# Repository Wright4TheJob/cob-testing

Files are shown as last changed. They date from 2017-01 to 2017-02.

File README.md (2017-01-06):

# cob-testing
Software for evaluation of cob blocks being tested at The University of Tulsa.
The data logging program monitors ambient temperature and humidity and internal moisture for up to 8 direct moisture resistance sensors. Data is taken at regular intervals and written at each interval to a text file for insurance against power outage. 

The system is built on a raspberry pi, currently running on a Pi 2 model B.

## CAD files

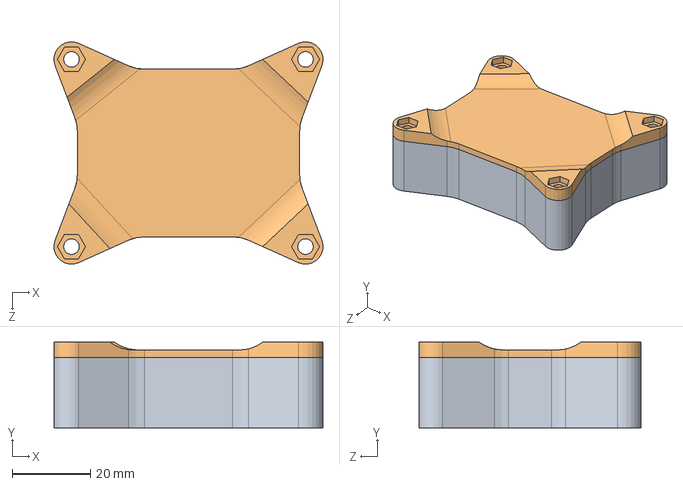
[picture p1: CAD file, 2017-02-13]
Electronics/Case/Assembly.SLDASM
69.0 x 22.0 x 57.0 mm
SensorHubTop
SensorHubPlate

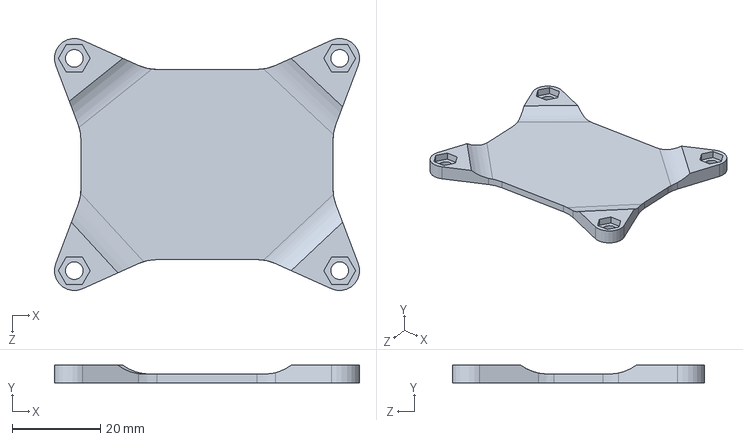
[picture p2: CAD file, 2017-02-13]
Electronics/Case/SensorHubPlate.SLDPRT
69.0 x 4.00 x 57.0 mm

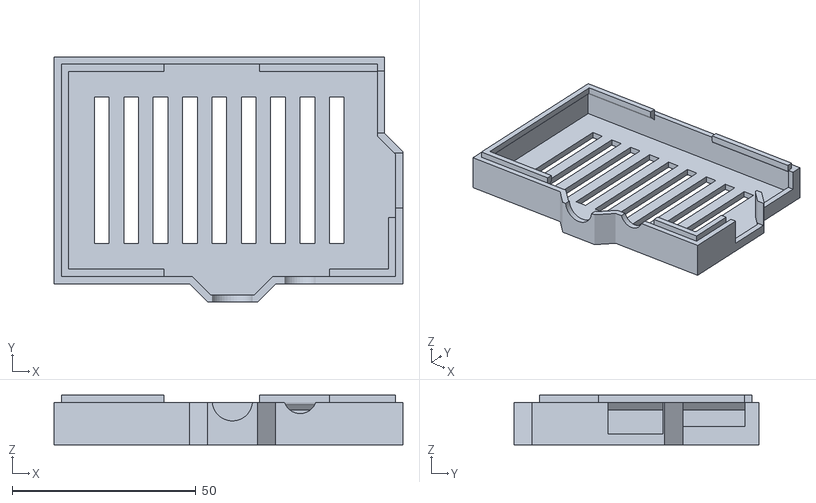
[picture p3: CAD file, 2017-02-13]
Electronics/Case/RasPi_Case2_Top_Vented.stl
95.0 x 66.8 x 13.5

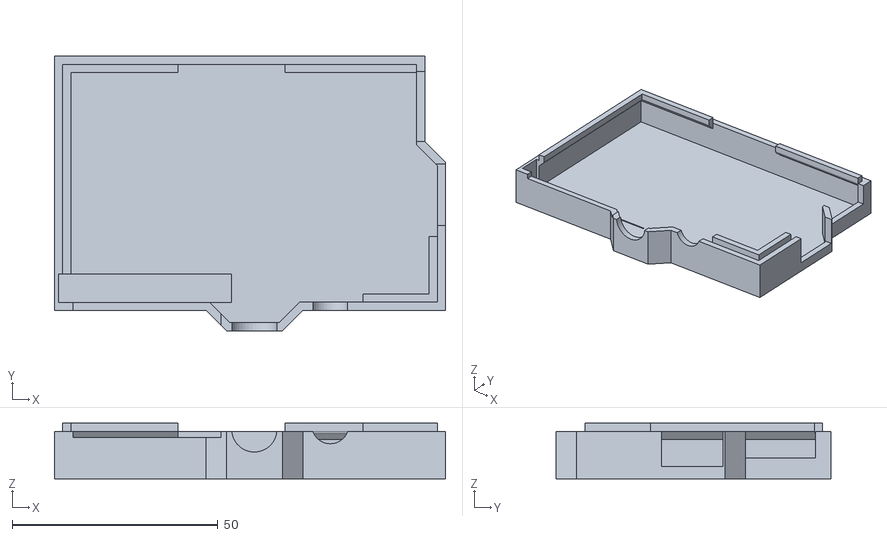
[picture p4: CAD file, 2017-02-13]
Electronics/Case/ModifiedTop.stl
95.0 x 66.8 x 13.5

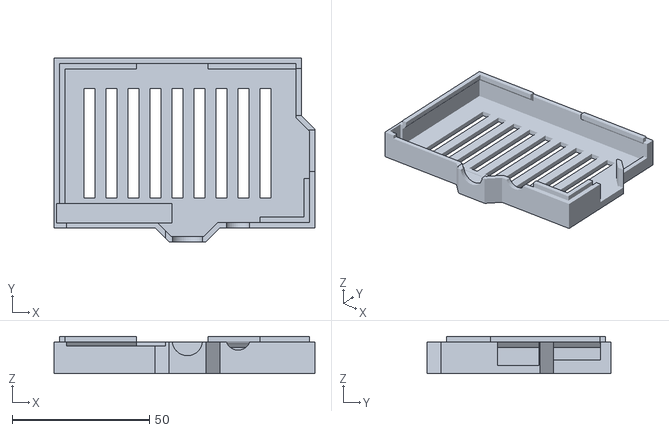
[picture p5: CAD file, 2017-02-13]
Electronics/Case/ModifiedTopVented.stl
95.0 x 66.8 x 13.5

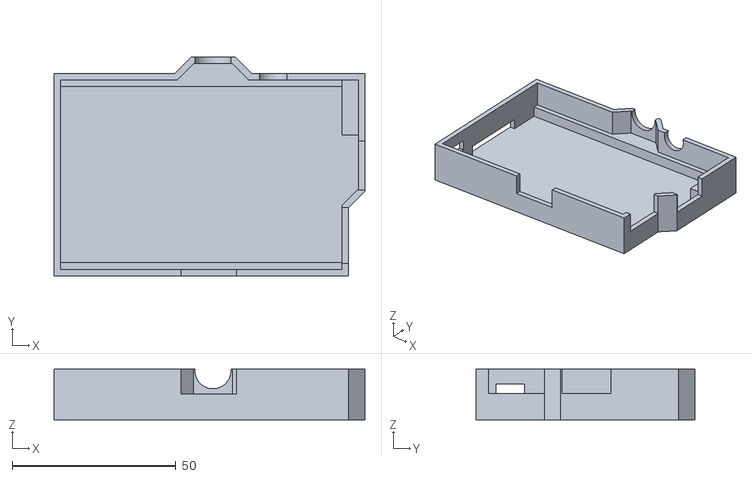
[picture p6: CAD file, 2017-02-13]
Electronics/Case/RasPi_Case2_Bottom_Final.stl
95.0 x 66.8 x 15.5

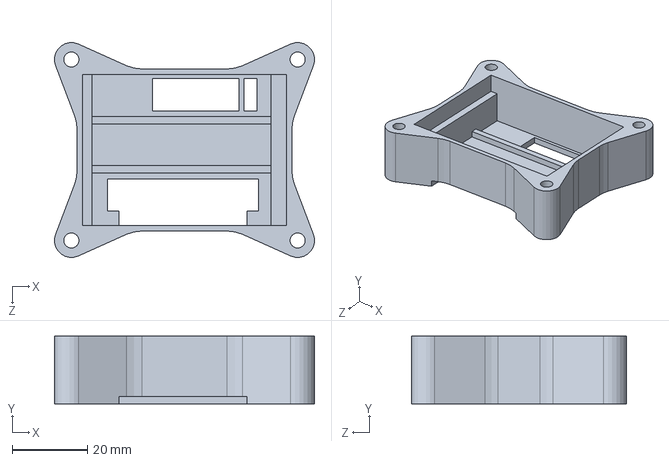
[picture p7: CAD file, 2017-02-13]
Electronics/Case/SensorHubTop.SLDPRT
69.0 x 18.0 x 57.0 mm

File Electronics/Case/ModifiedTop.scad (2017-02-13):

difference() {
    import("RasPi_Case2_Top_Vented.stl", convexity=20);
    translate([-43,-38,10])cube([36,15,5],centering=false);
    translate([-46.5,-26.5,1.75])cube([42,7,15],centering=false);
}

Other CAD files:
Electronics/Case/RasPi_Case2_Top.stl
Electronics/Case/SensorHubPlate.STL
Electronics/Case/SensorHubTop.STL

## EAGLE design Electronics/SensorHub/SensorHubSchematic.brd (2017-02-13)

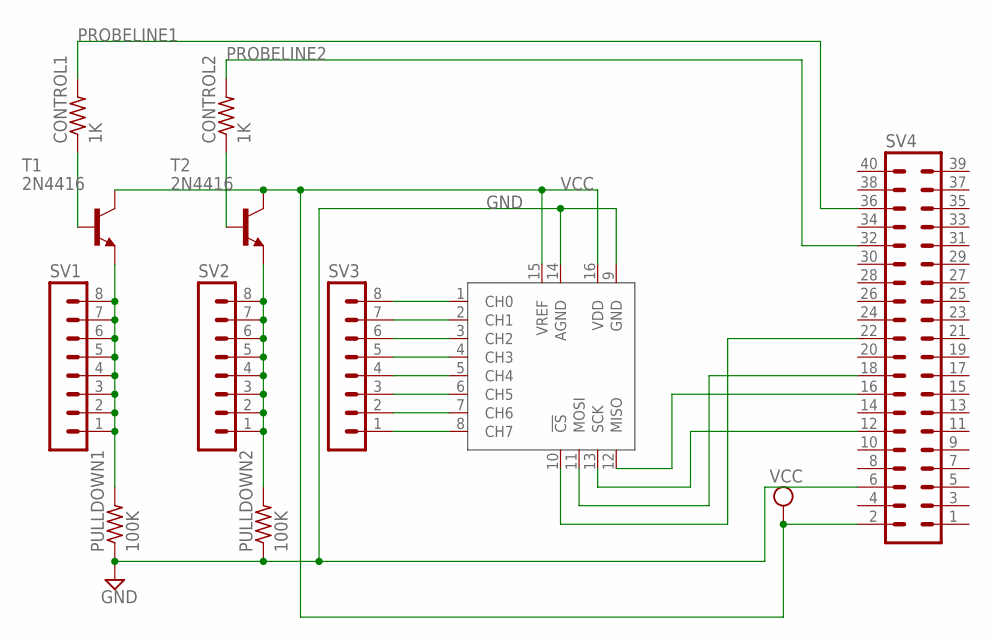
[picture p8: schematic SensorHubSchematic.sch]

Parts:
CONTROL1, CONTROL2: 1K; 0207/10
PULLDOWN1, PULLDOWN2: 100K; 0207/10
SV1, SV2, SV3: MA08-1
SV4: MA20-2
T1, T2: 2N4416; TO92
U$1: MCP3008P; DIL16

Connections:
GND: PULLDOWN1.1, PULLDOWN2.1, SV4.6, U$1.9 (GND), U$1.14 (AGND)
unnamed: PULLDOWN1.2, SV1.1, SV1.2, SV1.3, SV1.4, SV1.5, SV1.6, SV1.7, SV1.8, T1.3 (E)
unnamed: PULLDOWN2.2, SV2.1, SV2.2, SV2.3, SV2.4, SV2.5, SV2.6, SV2.7, SV2.8, T2.3 (E)
unnamed: SV3.1, U$1.8 (CH7)
unnamed: SV3.2, U$1.7 (CH6)
unnamed: SV3.3, U$1.6 (CH5)
unnamed: SV3.4, U$1.5 (CH4)
unnamed: SV3.5, U$1.4 (CH3)
unnamed: SV3.6, U$1.3 (CH2)
unnamed: SV3.7, U$1.2 (CH1)
unnamed: SV3.8, U$1.1 (CH0)
unnamed: CONTROL1.1, T1.2 (B)
unnamed: CONTROL2.1, T2.2 (B)
unnamed: SV4.18, U$1.11 (MOSI)
unnamed: SV4.22, U$1.10 (!CS)
unnamed: SV4.12, U$1.13 (SCK)
unnamed: SV4.16, U$1.12 (MISO)
PROBELINE1: CONTROL1.2, SV4.36
PROBELINE2: CONTROL2.2, SV4.32
VCC: SV4.2, T1.1 (C), T2.1 (C), U$1.15 (VREF), U$1.16 (VDD)

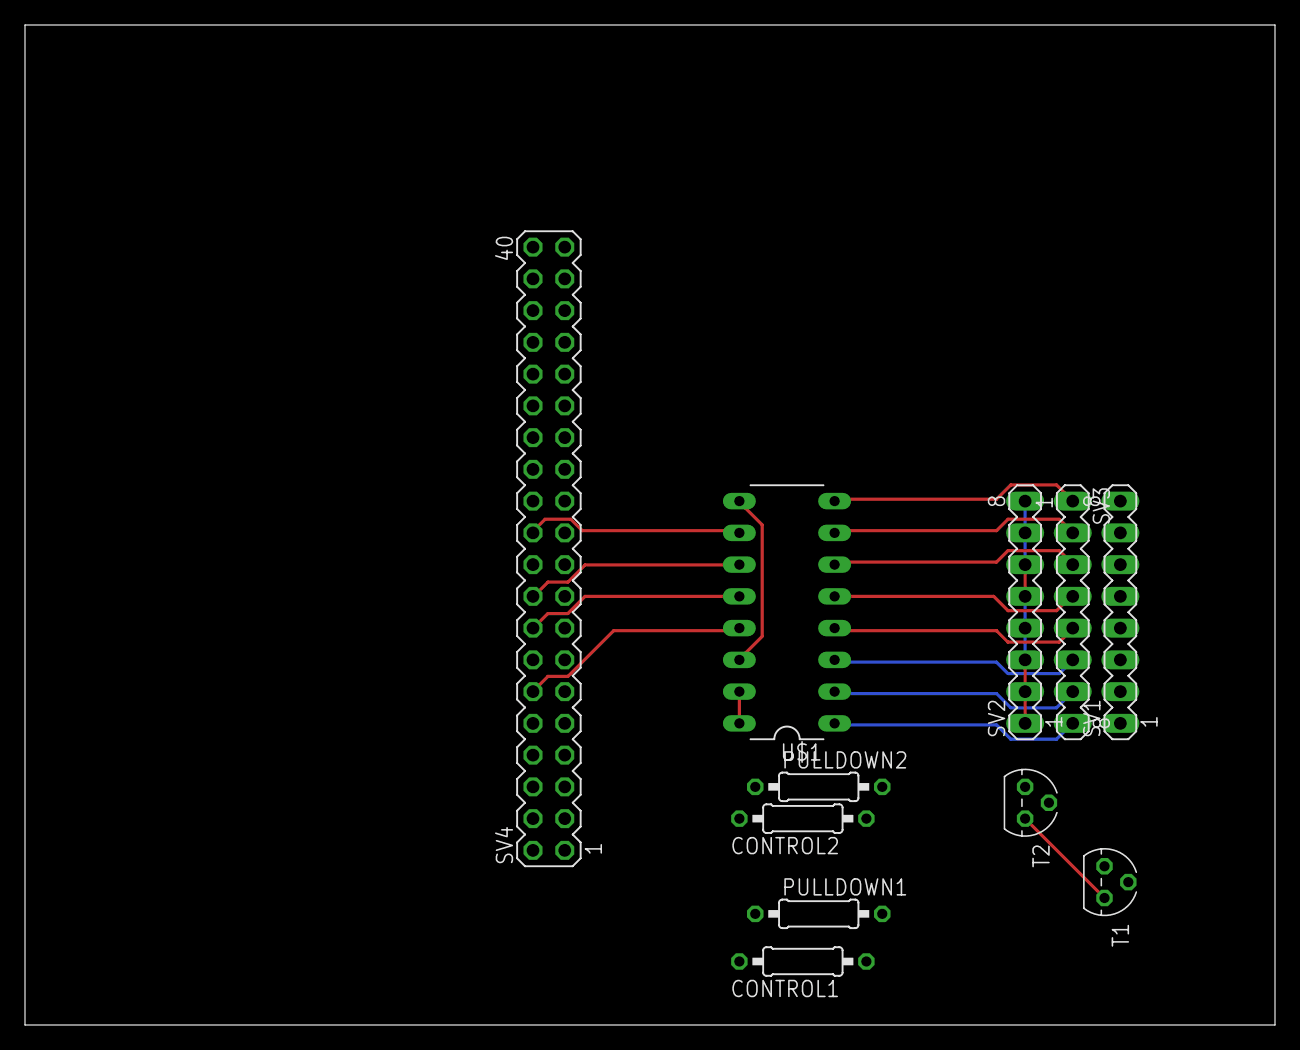
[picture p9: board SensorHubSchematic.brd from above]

Board: 2 copper layers, 100.0 x 80.0 mm, 11 parts (0 on the bottom side), 20 nets.

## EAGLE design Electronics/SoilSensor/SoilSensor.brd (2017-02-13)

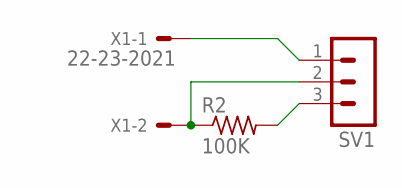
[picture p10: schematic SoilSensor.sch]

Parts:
R2: 100K; 0411/15
SV1: MA03-1
X1: 22-23-2021

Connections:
unnamed: SV1.1, X1.1
unnamed: R2.1, SV1.2, X1.2
unnamed: R2.2, SV1.3

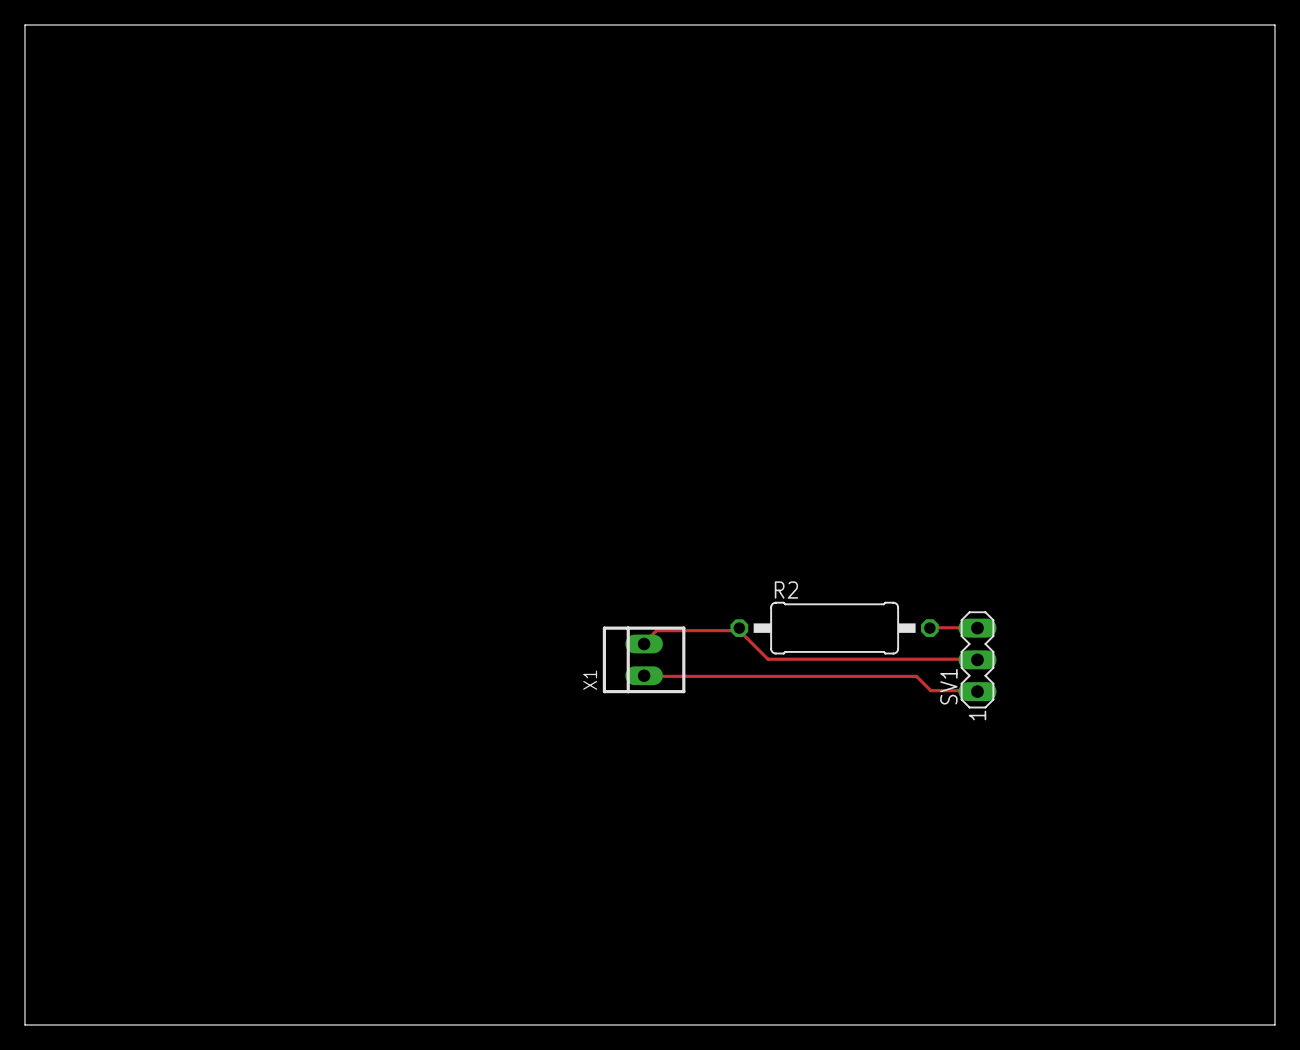
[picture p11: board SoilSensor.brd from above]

Board: 2 copper layers, 100.0 x 80.0 mm, 3 parts (0 on the bottom side), 3 nets.

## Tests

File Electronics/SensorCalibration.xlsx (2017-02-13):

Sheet: Theory
Moisture | Resistance | Sensor First | Resistor First | Constants:
 | 0 | 5 | 0 | Excitation: | 5 | V
 | 1000 | 4.95049505 | 0.0495049505 | R1: | 100000 | Ω
 | 2000 | 4.901960784 | 0.09803921569
 | 3000 | 4.854368932 | 0.145631068
 | 4000 | 4.807692308 | 0.1923076923
 | 5000 | 4.761904762 | 0.2380952381
 | 6000 | 4.716981132 | 0.2830188679
 | 7000 | 4.672897196 | 0.3271028037
 | 8000 | 4.62962963 | 0.3703703704
 | 9000 | 4.587155963 | 0.4128440367
 | 10000 | 4.545454545 | 0.4545454545
 | 20000 | 4.166666667 | 0.8333333333
 | 30000 | 3.846153846 | 1.153846154
 | 40000 | 3.571428571 | 1.428571429
 | 50000 | 3.333333333 | 1.666666667
 | 60000 | 3.125 | 1.875
 | 70000 | 2.941176471 | 2.058823529
 | 80000 | 2.777777778 | 2.222222222
 | 90000 | 2.631578947 | 2.368421053
 | 100000 | 2.5 | 2.5
 | 110000 | 2.380952381 | 2.619047619
 | 120000 | 2.272727273 | 2.727272727
 | 130000 | 2.173913043 | 2.826086957
 | 140000 | 2.083333333 | 2.916666667
 | 150000 | 2 | 3
 | 160000 | 1.923076923 | 3.076923077
 | 170000 | 1.851851852 | 3.148148148
 | 180000 | 1.785714286 | 3.214285714
 | 190000 | 1.724137931 | 3.275862069
 | 200000 | 1.666666667 | 3.333333333
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

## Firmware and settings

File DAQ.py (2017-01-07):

import time
import os
import RPi.GPIO as GPIO
import Adafruit_DHT

GPIO.setmode(GPIO.BCM)

def safeFilename(baseFilename, suffix):
    filename = baseFilename
    validName = False
    increment = 0
    while validName == False:
        if os.path.isfile(filename):
            increment = increment+1
            filename =  baseFilename+ repr(increment) + suffix
        else:
            validName = True
    return filename

def safeWriteTextToFile(filename, text):
    # Accepts any string. Automatically add newline characters to the end. Closes the file at the end of writing
    file = open(filename,"a")
    text = text + '\n'
    file.write(text)
    file.close()

# Collect data point from temp/humidity sensor
def getEnvironmentData(pin):

    sensor = Adafruit_DHT.AM2302
    
    humidity, tempC = Adafruit_DHT.read_retry(sensor, pin)
    
    return (tempC, humidity)

def readadc(adcnum, clockpin, mosipin, misopin, cspin):
    # Read data from ADC, with 8 possible channels
    # adcnum - the channel to read from
    # clockpin - pin location of clock output
    # mosipin - pin location of mosi output
    # misopin - pin location of miso input
    # cspin - pin location of cs output
    
    if ((adcnum > 7) or (adcnum < 0)):
        return -1
    GPIO.output(cspin,True) # Bring CS high

    GPIO.output(clockpin, False) # Bring clock low
    GPIO.output(cspin, False) # Bring CS low

    commandout = adcnum
    commandout |= 0x18 # Start bit + single-ending bit
    commandout <<= 3 # Send only 5 bits now

    for i in range(5):
        if (commandout & 0x80):
            GPIO.output(mosipin, True)
        else:
            GPIO.output(mosipin, False)
        commandout <<= 1
        # Cycle clock between iterations of for loop
        GPIO.output(clockpin, True)
        GPIO.output(clockpin, False)

    adcout = 0
    # Read in one empty bit, one null bit and 10 adc bits
    for i in range(12):
        # Cycle clock to advance to next bit
        GPIO.output(clockpin, True)
        GPIO.output(clockpin, False)
        adcout <<= 1
        if (GPIO.input(misopin)):
            adcout|= 0x1

    GPIO.output(cspin, True)

    adcout >>= 1 # First bit is null so drop it
    return adcout # Returns floating point value for bit-wise collected number
        

def initializeADC():
    # constants
    spiClock = 18
    spiMiso = 23
    spiMosi = 24
    spiCs = 25

    probeLine1 = 17
    probeLine2 = 22

    #GPIO initialization
    GPIO.setup(spiMosi, GPIO.OUT)
    GPIO.setup(spiMiso, GPIO.IN)
    GPIO.setup(spiClock, GPIO.OUT)
    GPIO.setup(spiCs, GPIO.OUT)

    GPIO.setup(probeLine1, GPIO.OUT)
    GPIO.setup(probeLine2, GPIO.OUT)
    
def getMoistureData(isEven,n, delay):
    # constants
    spiClock = 18
    spiMiso = 23
    spiMosi = 24
    spiCs = 25

    probeLine1 = 17
    probeLine2 = 22

    sensorVoltages = [0.0]*8
    if isEven == True:
        # Turn on sensors - set transistor pin x high
        #print('Turning on even side sensors')
        GPIO.output(probeLine1, True)
    else:
        # Turn on sensors - set transistor pin y high
        #print('Turning on odd side sensors')
        GPIO.output(probeLine2, True)

    # Let everything equalize in soil before taking data
    #print("Waiting before taking data")
    time.sleep(delay)
    #print("About to take data")
    
    # Take data
    for sensor in range(n):
        sensorVoltages[sensor] = readadc(sensor, spiClock, spiMosi, spiMiso, spiCs)
        #print('Collecting Sensor ' + repr(sensor) + ' data')

    #print("Took data")
    # Set both transistor pins low
    GPIO.output(probeLine1, False)
    GPIO.output(probeLine2, False)
    
    return sensorVoltages

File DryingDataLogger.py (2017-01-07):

# Imports
import time
import os
import RPi.GPIO as GPIO
import datetime
import DAQ

GPIO.setmode(GPIO.BCM)
GPIO.setwarnings(False)

# Constants
ambientSensorPin = 4
filename = 'Data'
filenameSuffix = '.txt'
moistureSensorQuantity = 8
dataPointsPerHour = 60.0 # Up to 120 per hour (minimum of 30 second delay before reading data)
delayBeforeReadingData = 10 # Seconds
secondsPerPoint = 60.0*60.0/float(dataPointsPerHour)

# Create new data file 
filename = DAQ.safeFilename(filename, filenameSuffix)
headerString = 'Date and Time, Nominal Minutes, Temp [C], Humidity, Brick1, Brick2, Brick3, Brick4, Brick5, Brick6, Brick7, Brick8'
DAQ.safeWriteTextToFile(filename, headerString)
print(headerString)

# Initialize time and date
startDate = datetime.datetime.today()
DAQ.initializeADC()
# Loop and collect the data
shouldContinue = True
isEven = False
nominalTestMinutes = 0

while shouldContinue == True:
    nominalTestMinutes = nominalTestMinutes + 60.0/dataPointsPerHour
    dataPointStartDateTime = datetime.datetime.today()
    nextDataPointTime = dataPointStartDateTime + datetime.timedelta(seconds=secondsPerPoint)
    
    if isEven == True:
        isEven = False
    else:
        isEven = True
    #print("Getting ambient data")
    (temperature, humidity) = DAQ.getEnvironmentData(ambientSensorPin)
    #print("Getting moisture data")
    moistureSensorValues = DAQ.getMoistureData(isEven,moistureSensorQuantity, delayBeforeReadingData) 
    
    currentdatetime = datetime.datetime.today()
    timeSinceStarting = currentdatetime - startDate

    dateTimeString = currentdatetime.isoformat(' ')

    dataString = dateTimeString + ', ' + repr(nominalTestMinutes) + ', ' + repr(temperature) + ', ' + repr(humidity)
    for i in range(moistureSensorQuantity):
        dataString = dataString + ', ' + repr(moistureSensorValues[i])

    DAQ.safeWriteTextToFile(filename, dataString)
    print(dataString)
    dataString = ""
    
    if isEven == True:
        isEven = False
    else:
        isEven = True
        
    # Reverse polarity on the sensors for euqal duration to minimize galvanic corrosion
    DAQ.getMoistureData(isEven,moistureSensorQuantity, delayBeforeReadingData) 

    now = datetime.datetime.today()

    #print("About to wait for next data point")
    while now < nextDataPointTime:
        now = datetime.datetime.today()
    #print("About to start new data point")

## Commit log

2017-01-07 Got delays working properly. Ambient sensor timing out without being plugged in. Test with sensor later
2017-02-13 Electronics documentation added
    [Assembly.SLDASM, ModifiedTop.scad, ModifiedTop.stl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]
